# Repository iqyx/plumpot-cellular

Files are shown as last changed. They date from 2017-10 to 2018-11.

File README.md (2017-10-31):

plumpot-cellular
===================

A plumpot series base board with a sub-1GHz radio and a 2.5G cellular modem

Features
--------------------

- half-length, half-width form factor (80x50mm)
- mounting holes for half-length half-width and half-length quarter-width extension boards
- two extension bus connectors (UXB1 compatible - multidrop half-duplex SPI bus, I2C bus, wakeup request, interrupt request and 5V power)
- AX5243 sub-1GHz radio module with a 50ohm MMCX antenna connector
- Quectel M66 2.5G GPRS/EDGE cellular modem with a 50ohm MMCX antenna connector and network activity LED indicators
- 6-60Vin power supply step down regulator for providing system and bus power (5V, 0.2A)
- micro-B USB port with a CP2101 serial to USB bridge (console access and power input)
- RTC with a CR1220 lithium coin cell backup

The board is developed as an open source hardware using tools freely available for non-
commercial usage. It is able to run free and non-free commercial software without any
restrictions. It is not locked to a specific firmware and contains a standard 10-pin Cortex Debug
connector. A multitude of free and commercial development tools exist to develop and modify the
firmware for the board.

History
----------------

This is a uNodeX form-factor version of the qNode4 board (hence the previous name "unodex-connect-42").

I accepted a set of rules for board design, sizes, mounting types and board communication
to ease the development of new hardware. Such hardware could be easily connected together
to form wireless nodes for IoT/IoM and similar usages and enables you to do data acquisition,
data forwarding/communication, control, etc. I started to call this platform "uNodeX"
(micro node - extendable).

This is a rework of the previous qNode4 board to be compatible with the uNodeX platform,
with a slightly modified hardware:

- step-up converter for battery charging is removed
- RF connectors are changed to MMCX
- uNodeX bus connectors are added
- board dimensions are changed to 50x80mm (uNodeX half-width, half-depth)
- CP2102 USB to serial converter for console access
- VBUS power oring controller for uNodeX bus
- 6-60VDC step-down converter is added
- temperature sensor is removed

The board includes only a reduced set of hardware to fulfill the following requirements:

- to be a mainboard for HWHD or QWHD cards
- to provide power for them
- to enable them to communicate over the air (uMesh stack or GPRS/EDGE)

I started to call this board "plumpot" as it is mainly used to run the plumCore firmware.

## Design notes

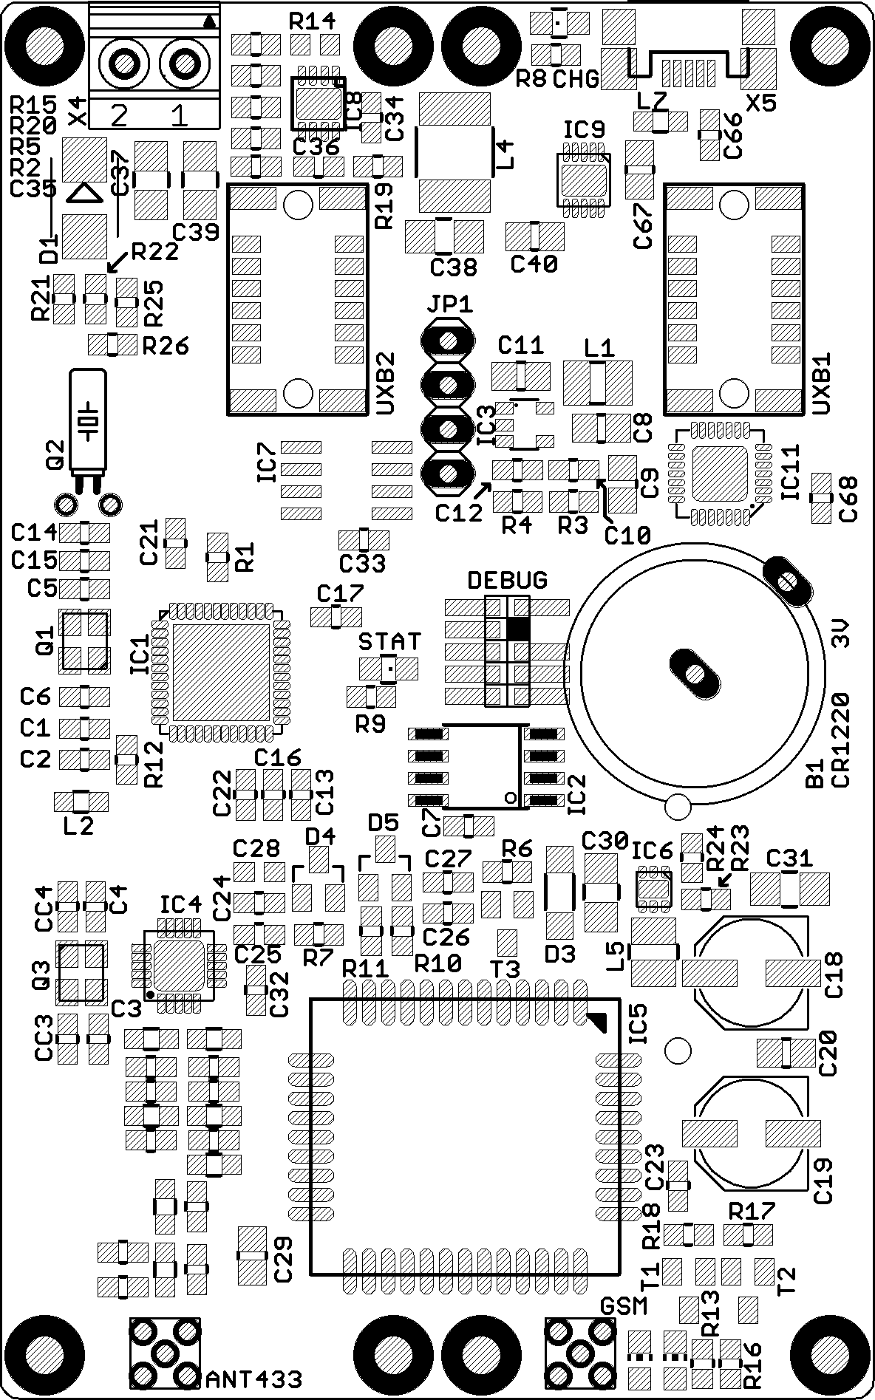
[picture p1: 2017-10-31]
doc/board_layout.png

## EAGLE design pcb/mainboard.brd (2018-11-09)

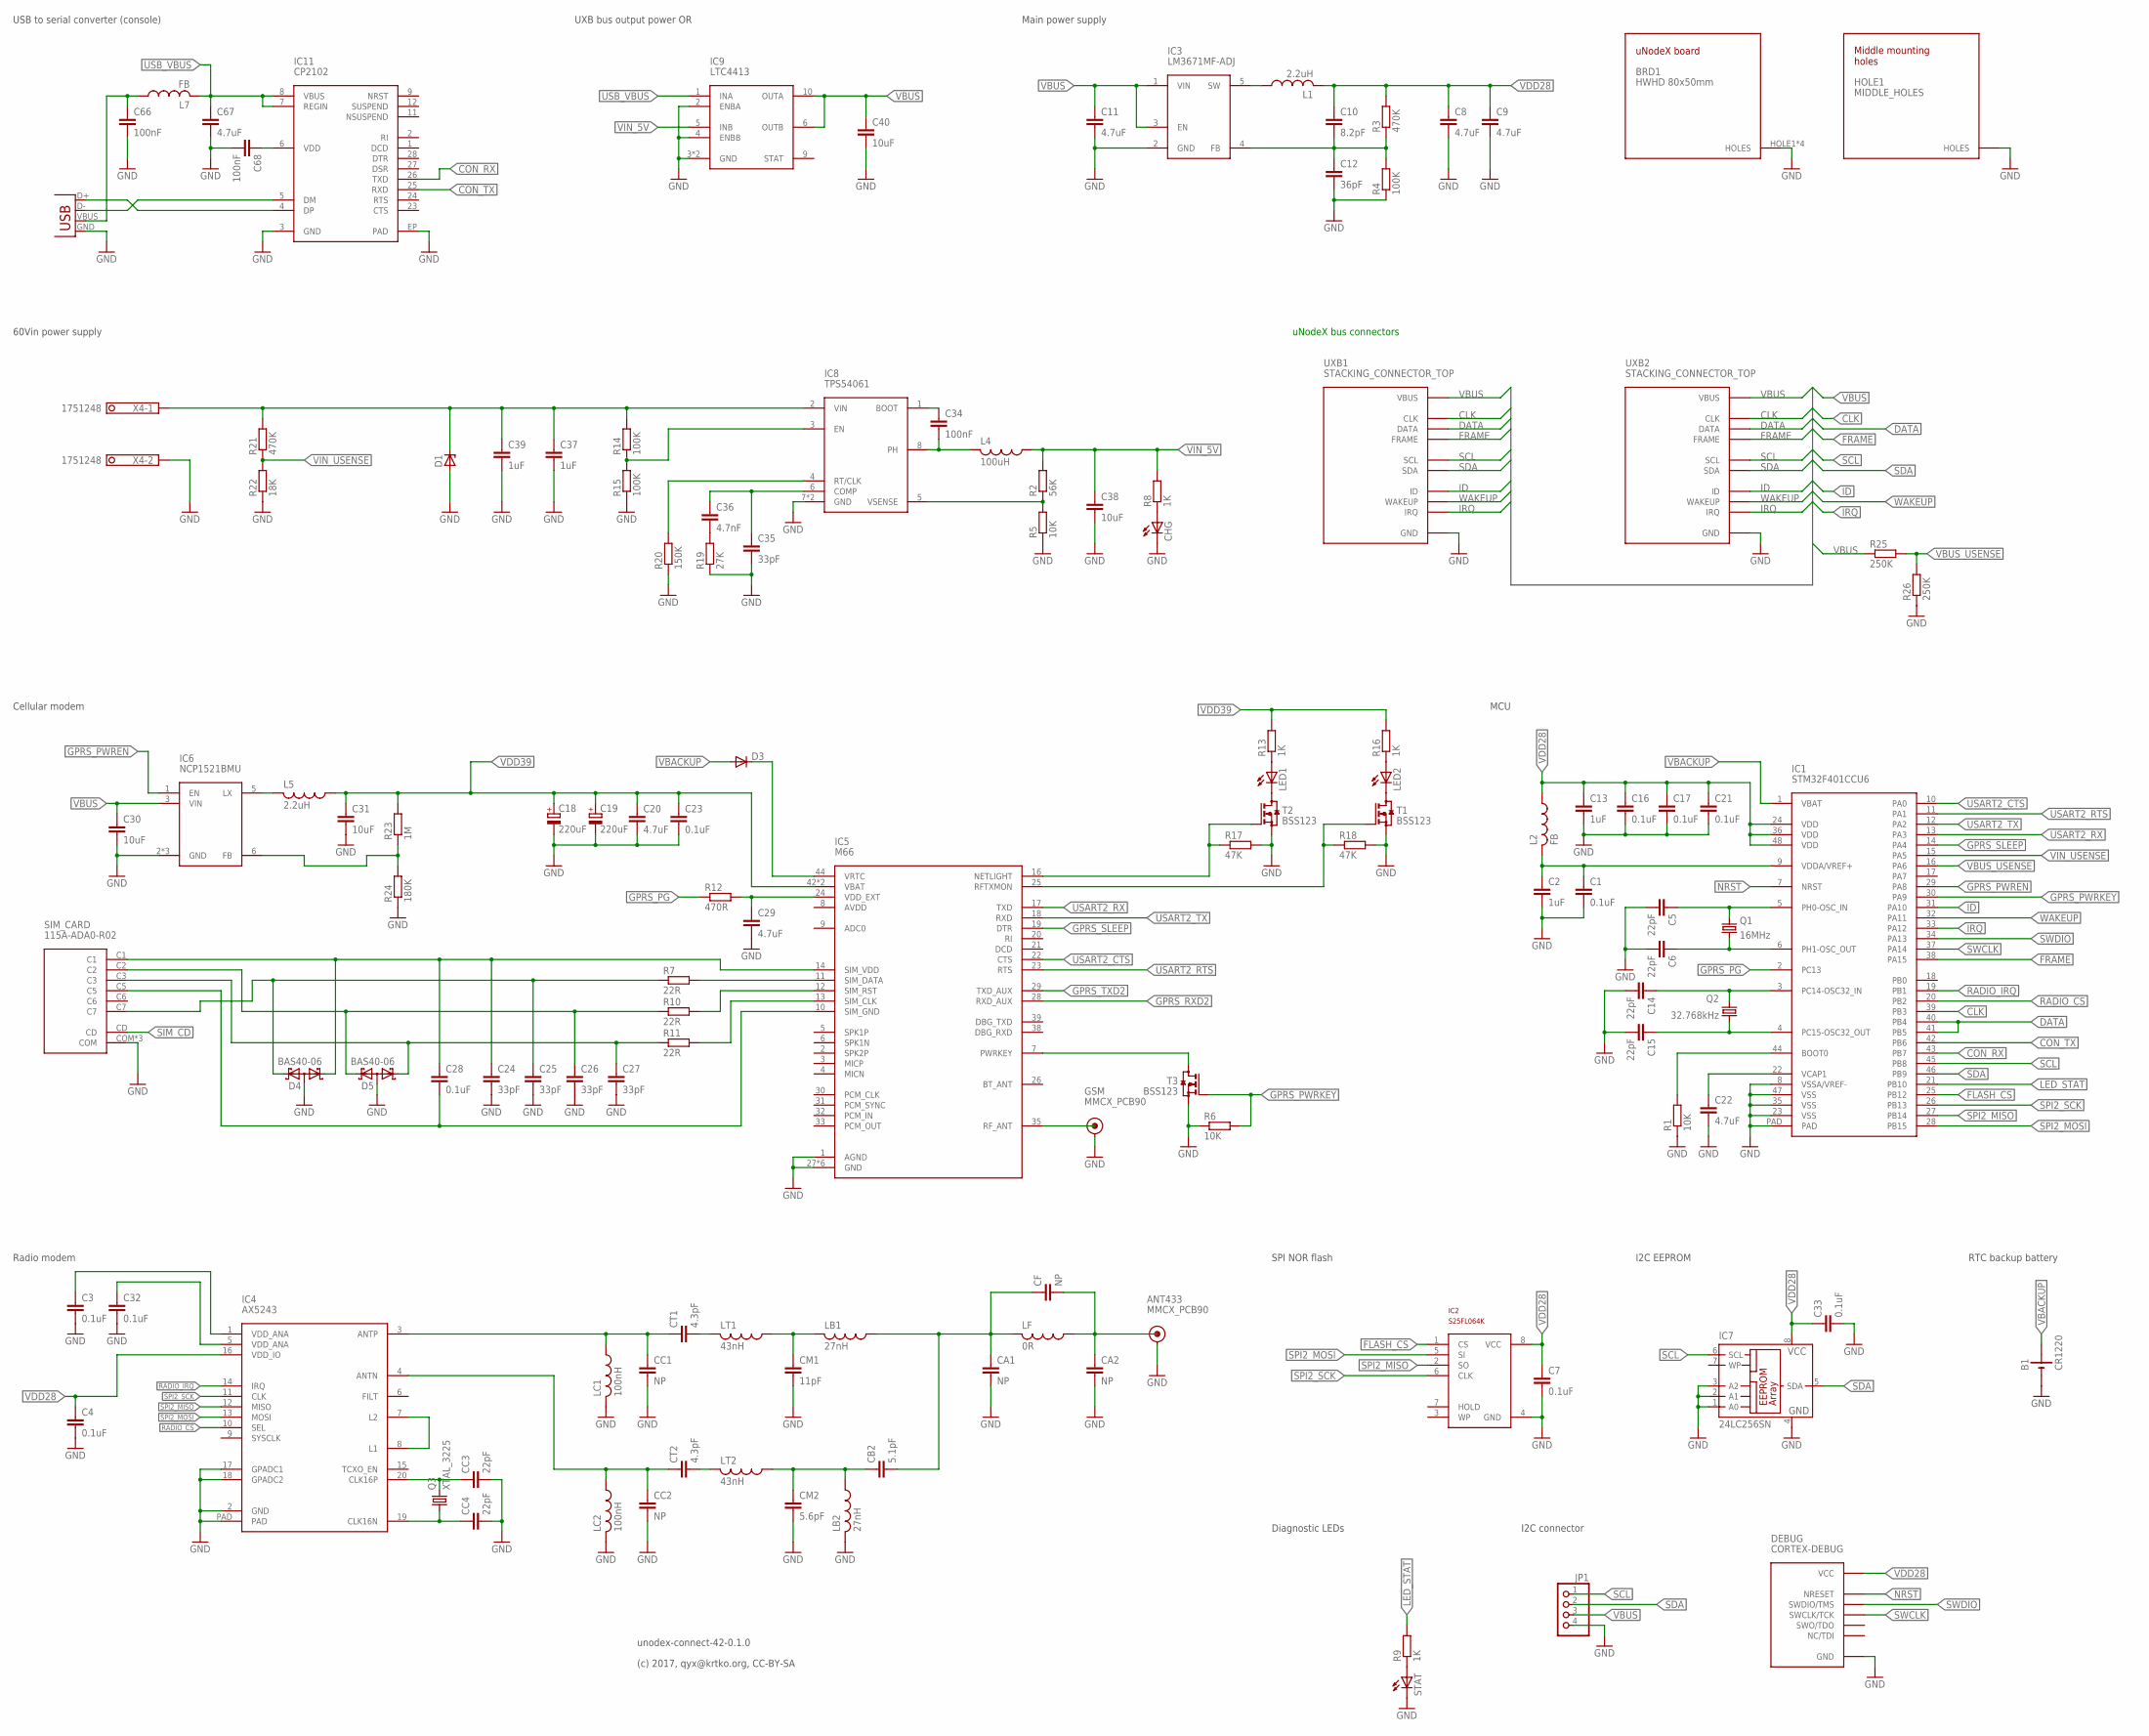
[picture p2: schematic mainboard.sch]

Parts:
ANT433: MMCX_PCB90; MMCX_PCB_90
B1: CR1220; CONNFLY_CR1220
BRD1: HWHD 80x50mm; HWHD_SHARP_CORNERS
C1, C3, C4, C7, C16, C17, C21, C23, C28, C32, C33: 0.1uF; C0603
C2, C13: 1uF; C0603
C5, C6, C14, C15: 22pF; C0603
C8, C9, C11, C20, C29, C67: 4.7uF; C0805
C10: 8.2pF; C0603
C12: 36pF; C0603
C18, C19: 220uF; PANASONIC_D
C22: 4.7uF; C0603
C24, C25, C26, C27, C35: 33pF; C0603
C30, C31, C38: 10uF; C1206
C34, C66, C68: 100nF; C0603
C36: 4.7nF; C0603
C37, C39: 1uF; C1206
C40: 10uF; C0805
CA1, CA2: NP; C0603
CB2: 5.1pF; C0603
CC1, CC2: NP; C0603
CC3, CC4: 22pF; C0603
CF: NP; C0603
CHG: LEDCHIPLED_0805; CHIPLED_0805
CM1: 11pF; C0603
CM2: 5.6pF; C0603
CT1, CT2: 4.3pF; C0603
D1: ZENER-DIODESMB; SMB
D3: DIODE-SOD123; SOD123
D4, D5: BAS40-06; SOT23
DEBUG: CORTEX-DEBUG
GSM: MMCX_PCB90; MMCX_PCB_90
HOLE1: MIDDLE_HOLES
IC1: STM32F401CCU6; UFQFPN48
IC2: S25FL064K; SO-08M
IC3: LM3671MF-ADJ; SOT23-5
IC4: AX5243; QFN20
IC5: M66
IC6: NCP1521BMU; UDFN6
IC7: 24LC256SN; SO-08
IC8: TPS54061; WSON8
IC9: LTC4413; DFN10
IC11: CP2102; QFN28
JP1: PINHD-1X4; 1X04
L1, L5: 2.2uH; L2825P
L2, L7: FB; L2012C
L4: 100uH; L5650M
LB1, LB2: 27nH; L2012C
LC1, LC2: 100nH; L2012C
LED1, LED2: LEDCHIP-LED0805; CHIP-LED0805
LF: 0R; L2012C
LT1, LT2: 43nH; L2012C
Q1: 16MHz; XTAL_3225
Q2: 32.768kHz; TC26H
Q3: XTAL_3225
R1, R5, R6: 10K; R0603
R2: 56K; R0603
R3, R21: 470K; R0603
R4, R14, R15: 100K; R0603
R7, R10, R11: 22R; R0603
R8, R9, R13, R16: 1K; R0603
R12: 470R; R0603
R17, R18: 47K; R0603
R19: 27K; R0603
R20: 150K; R0603
R22: 18K; R0603
R23: 1M; R0603
R24: 180K; R0603
R25, R26: 250K; R0603
SIM_CARD: 115A-ADA0-R02
STAT: LEDCHIPLED_0805; CHIPLED_0805
T1, T2, T3: BSS123; SOT23
UXB1, UXB2: STACKING_CONNECTOR_TOP; HAR-FLEX-TOP-12P
X4: 1751248
X5: USB-MICROB

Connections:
ANT: ANT433.C (CENTER), CA2.1, CF.2, LF.1
ANTN: CC2.1, CT2.1, IC4.4 (ANTN), LC2.1
ANTP: CC1.1, CT1.1, IC4.3 (ANTP), LC1.1
CLK: IC1.39 (PB3), UXB1.CLK, UXB2.CLK
CON_RX: IC1.43 (PB7), IC11.26 (TXD)
CON_TX: IC1.42 (PB6), IC11.25 (RXD)
DATA: IC1.40 (PB4), IC1.41 (PB5), UXB1.DATA, UXB2.DATA
FLASH_CS: IC1.25 (PB12), IC2.1 (CS)
FRAME: IC1.38 (PA15), UXB1.FRAME, UXB2.FRAME
GND: ANT433.S1 (SHIELD), ANT433.S2 (SHIELD), ANT433.S3 (SHIELD), ANT433.S4 (SHIELD), B1.NEG (-), BRD1.HOLE1, BRD1.HOLE2, BRD1.HOLE3, BRD1.HOLE4, C1.2, C2.2, C3.2, C4.2, C5.2, C6.2, C7.2, C8.2, C9.2, C11.2, C12.2, C13.2, C14.2, C15.2, C16.2, C17.2, C18.-, C19.-, C20.2, C21.2, C22.2, C23.2, C24.2, C25.2, C26.2, C27.2, C29.2, C30.2, C31.2, C32.2, C33.2, C35.2, C37.2, C38.2, C39.2, C40.2, C66.2, C67.2, C68.2, CA1.2, CA2.2, CC1.2, CC2.2, CC3.2, CC4.2, CHG.C, CM1.2, CM2.2, D1.A, D4.3 (AA), D5.3 (AA), DEBUG.GND1 (GND), DEBUG.GND2 (GND), DEBUG.GND_DETECT (GND), GSM.S1 (SHIELD), GSM.S2 (SHIELD), GSM.S3 (SHIELD), GSM.S4 (SHIELD), HOLE1.P$1, HOLE1.P$2, HOLE1.P$3, HOLE1.P$4, IC1.8 (VSSA/VREF-), IC1.23 (VSS), IC1.35 (VSS), IC1.47 (VSS), IC1.PAD, IC2.4 (GND), IC3.2 (GND), IC4.2 (GND), IC4.17 (GPADC1), IC4.18 (GPADC2), IC4.PAD, IC5.1 (AGND), IC5.27 (GND), IC5.34 (GND), IC5.36 (GND), IC5.37 (GND), IC5.40 (GND), IC5.41 (GND), IC6.2 (GND), IC6.4 (GND), IC6.PAD (GND), IC7.1 (A0), IC7.2 (A1), IC7.3 (A2), IC7.4 (GND), IC8.7 (GND), IC8.PAD (GND), IC9.2 (ENBA), IC9.3 (GND), IC9.4 (ENBB), IC9.PAD (GND), IC11.3 (GND), IC11.EP (PAD), JP1.4, LB2.2, LC1.2, LC2.2, R1.1, R4.1, R5.1, R6.1, R15.1, R17.2, R18.2, R19.1, R20.1, R22.1, R24.1, R26.1, SIM_CARD.COM, SIM_CARD.H1 (COM), SIM_CARD.H2 (COM), STAT.C, T1.2 (S), T2.2 (S), T3.2 (S), UXB1.GND1 (GND), UXB1.GND2 (GND), UXB1.GND3 (GND), UXB1.H1 (GND), UXB1.H2 (GND), UXB1.H3 (GND), UXB1.H4 (GND), UXB2.GND1 (GND), UXB2.GND2 (GND), UXB2.GND3 (GND), UXB2.H1 (GND), UXB2.H2 (GND), UXB2.H3 (GND), UXB2.H4 (GND), X4.2, X5.GND
GPRS_PG: IC1.2 (PC13), R12.1
GPRS_PWREN: IC1.29 (PA8), IC6.1 (EN)
GPRS_PWRKEY: IC1.30 (PA9), R6.2, T3.1 (G)
GPRS_RXD2: IC5.28 (RXD_AUX)
GPRS_SLEEP: IC1.14 (PA4), IC5.19 (DTR)
GPRS_TXD2: IC5.29 (TXD_AUX)
ID: IC1.31 (PA10), UXB1.ID, UXB2.ID
IRQ: IC1.33 (PA12), UXB1.IRQ, UXB2.IRQ
LED_STAT: IC1.21 (PB10), R9.2
unnamed: CHG.A, R8.1
unnamed: C1.1, C2.1, IC1.9 (VDDA/VREF+), L2.2
unnamed: IC3.5 (SW), L1.1
unnamed: C5.1, IC1.5 (PH0-OSC_IN), Q1.3 (2)
unnamed: C22.1, IC1.22 (VCAP1)
unnamed: R9.1, STAT.A
unnamed: C10.2, C12.1, IC3.4 (FB), R3.1, R4.2
unnamed: C6.1, IC1.6 (PH1-OSC_OUT), Q1.1
unnamed: C14.1, IC1.3 (PC14-OSC32_IN), Q2.2
unnamed: C15.1, IC1.4 (PC15-OSC32_OUT), Q2.1
unnamed: IC1.44 (BOOT0), R1.2
unnamed: D3.C, IC5.44 (VRTC)
unnamed: IC5.25 (RFTXMON), R18.1, T1.1 (G)
unnamed: C34.2, IC8.8 (PH), L4.2
unnamed: C34.1, IC8.1 (BOOT)
unnamed: IC8.5 (VSENSE), R2.1, R5.2
unnamed: GSM.C (CENTER), IC5.35 (RF_ANT)
unnamed: IC5.7 (PWRKEY), T3.3 (D)
unnamed: LED1.C, T2.3 (D)
unnamed: C29.1, IC5.24 (VDD_EXT), R12.2
unnamed: LED2.C, T1.3 (D)
unnamed: LED1.A, R13.1
unnamed: LED2.A, R16.1
unnamed: IC5.16 (NETLIGHT), R17.1, T2.1 (G)
unnamed: IC11.4 (DP), X5.D+
unnamed: IC11.5 (DM), X5.D-
unnamed: CA1.1, CB2.2, CF.1, LB1.1, LF.2
unnamed: CT1.2, LT1.2
unnamed: CM1.1, LB1.2, LT1.1
unnamed: CT2.2, LT2.2
unnamed: CB2.1, CM2.1, LB2.1, LT2.1
unnamed: C3.1, IC4.1 (VDD_ANA)
unnamed: IC4.7 (L2), IC4.8 (L1)
unnamed: C32.1, IC4.5 (VDD_ANA)
unnamed: CC3.1, IC4.20 (CLK16P), Q3.3 (2)
unnamed: CC4.1, IC4.19 (CLK16N), Q3.1
unnamed: C36.2, R19.2
unnamed: C35.1, C36.1, IC8.6 (COMP)
unnamed: IC8.4 (RT/CLK), R20.2
unnamed: IC6.5 (LX), L5.2
unnamed: C37.1, C39.1, D1.C, IC8.2 (VIN), R14.2, R21.2, X4.1
unnamed: IC8.3 (EN), R14.1, R15.2
unnamed: IC6.6 (FB), R23.1, R24.2
unnamed: C66.1, L7.1, X5.VBUS
unnamed: C68.1, IC11.6 (VDD)
NRST: DEBUG.NRESET, IC1.7 (NRST)
RADIO_CS: IC1.20 (PB2), IC4.10 (SEL)
RADIO_IRQ: IC1.19 (PB1), IC4.14 (IRQ)
SCL: IC1.45 (PB8), IC7.6 (SCL), JP1.1, UXB1.SCL, UXB2.SCL
SDA: IC1.46 (PB9), IC7.5 (SDA), JP1.2, UXB1.SDA, UXB2.SDA
SIM_CD: SIM_CARD.CD
SIM_CLK: IC5.13 (SIM_CLK), R11.2
SIM_CLK_R: C27.1, D5.1 (K1), R11.1, SIM_CARD.C3
SIM_DATA: IC5.11 (SIM_DATA), R7.2
SIM_DATA_R: C25.1, D4.2 (K2), R7.1, SIM_CARD.C7
SIM_GND: C28.2, IC5.10 (SIM_GND), SIM_CARD.C5
SIM_RST: IC5.12 (SIM_RST), R10.2
SIM_RST_R: C26.1, D5.2 (K2), R10.1, SIM_CARD.C2
SIM_VDD: C24.1, C28.1, D4.1 (K1), IC5.14 (SIM_VDD), SIM_CARD.C1
SPI2_MISO: IC1.27 (PB14), IC2.2 (SO), IC4.12 (MISO)
SPI2_MOSI: IC1.28 (PB15), IC2.5 (SI), IC4.13 (MOSI)
SPI2_SCK: IC1.26 (PB13), IC2.6 (CLK), IC4.11 (CLK)
SWCLK: DEBUG.SWCLK/TCK, IC1.37 (PA14)
SWDIO: DEBUG.SWDIO/TMS, IC1.34 (PA13)
USART2_CTS: IC1.10 (PA0), IC5.22 (CTS)
USART2_RTS: IC1.11 (PA1), IC5.23 (RTS)
USART2_RX: IC1.13 (PA3), IC5.17 (TXD)
USART2_TX: IC1.12 (PA2), IC5.18 (RXD)
USB_VBUS: C67.1, IC9.1 (INA), IC11.7 (REGIN), IC11.8 (VBUS), L7.2
VBACKUP: B1.POS (+), D3.A, IC1.1 (VBAT)
VBUS: C11.1, C30.1, C40.1, IC3.1 (VIN), IC3.3 (EN), IC6.3 (VIN), IC9.6 (OUTB), IC9.10 (OUTA), JP1.3, R25.1, UXB1.VBUS, UXB2.VBUS
VBUS_USENSE: IC1.16 (PA6), R25.2, R26.2
VDD28: C4.1, C7.1, C8.1, C9.1, C10.1, C13.1, C16.1, C17.1, C21.1, C33.1, DEBUG.VCC, IC1.24 (VDD), IC1.36 (VDD), IC1.48 (VDD), IC2.8 (VCC), IC4.16 (VDD_IO), IC7.8 (VCC), L1.2, L2.1, R3.2
VDD39: C18.+, C19.+, C20.1, C23.1, C31.1, IC5.42 (VBAT), IC5.43 (VBAT), L5.1, R13.2, R16.2, R23.2
VIN_5V: C38.1, IC9.5 (INB), L4.1, R2.2, R8.2
VIN_USENSE: IC1.15 (PA5), R21.1, R22.2
WAKEUP: IC1.32 (PA11), UXB1.WAKEUP, UXB2.WAKEUP

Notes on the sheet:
SPI NOR flash
Diagnostic LEDs
MCU
uNodeX bus connectors
USB to serial converter (console)
UXB bus output power OR
Main power supply
60Vin power supply
Cellular modem
Radio modem
I2C connector
RTC backup battery
I2C EEPROM
unodex-connect-42-0.1.0
(c) 2017, qyx@krtko.org, CC-BY-SA

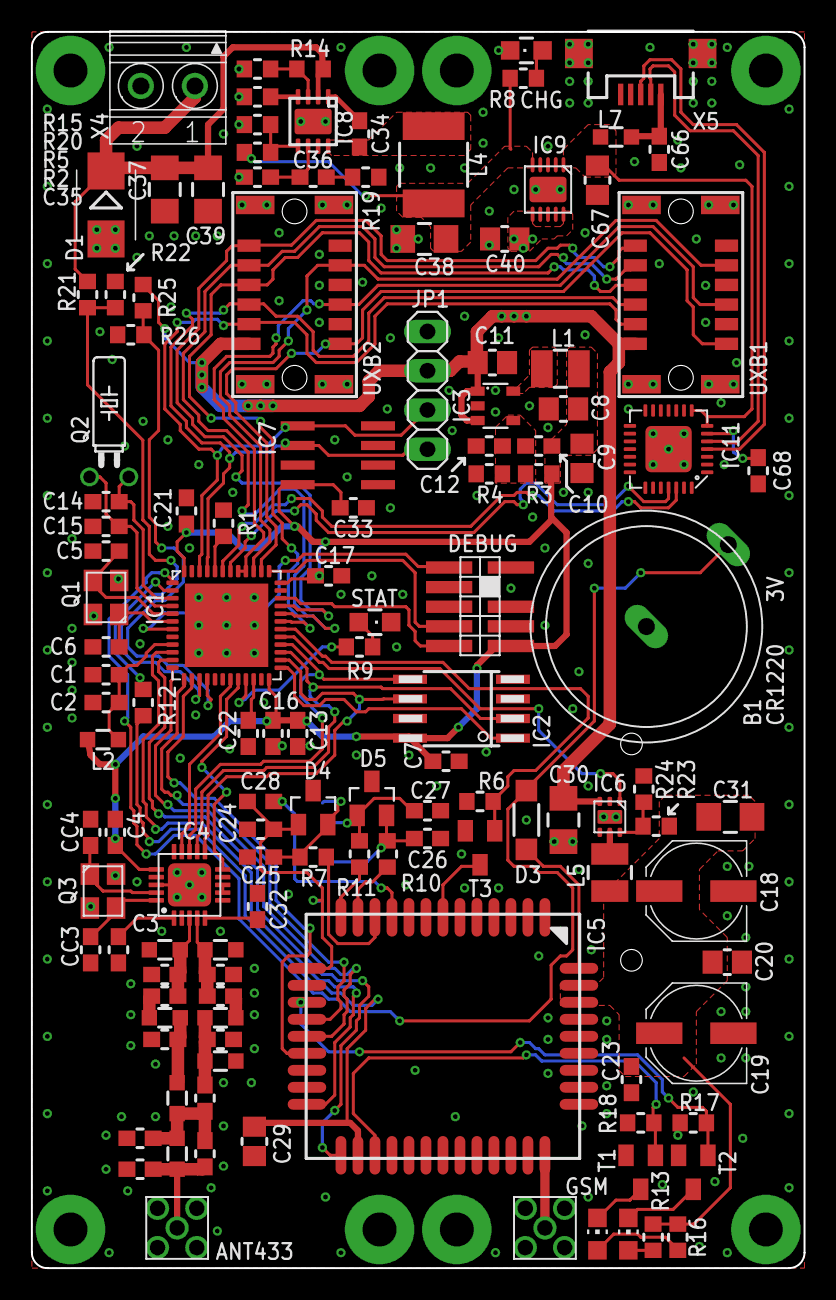
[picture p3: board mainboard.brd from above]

Board: 2 copper layers, 50.0 x 80.0 mm, 129 parts (1 on the bottom side), 93 nets.

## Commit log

2017-10-31 Add schematic and layout of the board
    [mainboard.brd, mainboard.sch]
2017-10-31 Add generated Gerber outputs (for seeedstudio)
    [mainboard.GBL, mainboard.GBO, mainboard.GBP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]
2017-10-31 Add board documentation draft
2018-11-09 Add a to-do list for the next board revision
    [mainboard.brd, mainboard.sch]

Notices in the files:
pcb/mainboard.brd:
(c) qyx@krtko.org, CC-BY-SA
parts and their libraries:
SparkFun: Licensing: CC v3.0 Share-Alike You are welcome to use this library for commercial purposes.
